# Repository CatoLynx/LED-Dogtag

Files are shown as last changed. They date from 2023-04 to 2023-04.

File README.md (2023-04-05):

# LED Dogtag
Here you can find the hardware and software for my LED display dogtag.

# Repository Structure
* The `hardware/LED_Dogtag_HW` directory contains the hardware design and production files for the dogtag
* The `hardware/LED_Driver_Evaluation` directory contains the hardware design and production files for an evaluation/test board for the LED driver IC

## Licenses
The hardware part of this repository is licensed under the CERN Open Hardware Licence Version 2 - Strongly Reciprocal (CERN-OHL-S v2) or later.
The software part is licensed under the GNU General Public License v3 (GPLv3).

## Design Tools used
* Schematics and printed circuit board designs were made using KiCad 7
* 3D models were created using SolidWorks 2023

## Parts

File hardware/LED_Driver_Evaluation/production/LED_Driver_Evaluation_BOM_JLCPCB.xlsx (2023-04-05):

Comment | Designator | Footprint | JLCPCB Part #（optional）
1µF | C1 | C0603 | C15849
100nF | C2 | C0603 | C14663
NH-B1010RGBT-HF | D1-66 | LED0404 | C2874113
51R | R1,R4,R7,R11,R14,R17 | R0402 | C25125
20R | R2,R3,R5,R6,R8,R9,R12,R13,R15,R16,R18,R20 | R0402 | C310255
100k | R10 | R0603 | C25803
10k | R19 | R0402 | C25744
IS31FL3743B | U1 | UQFN-40 | C2962218

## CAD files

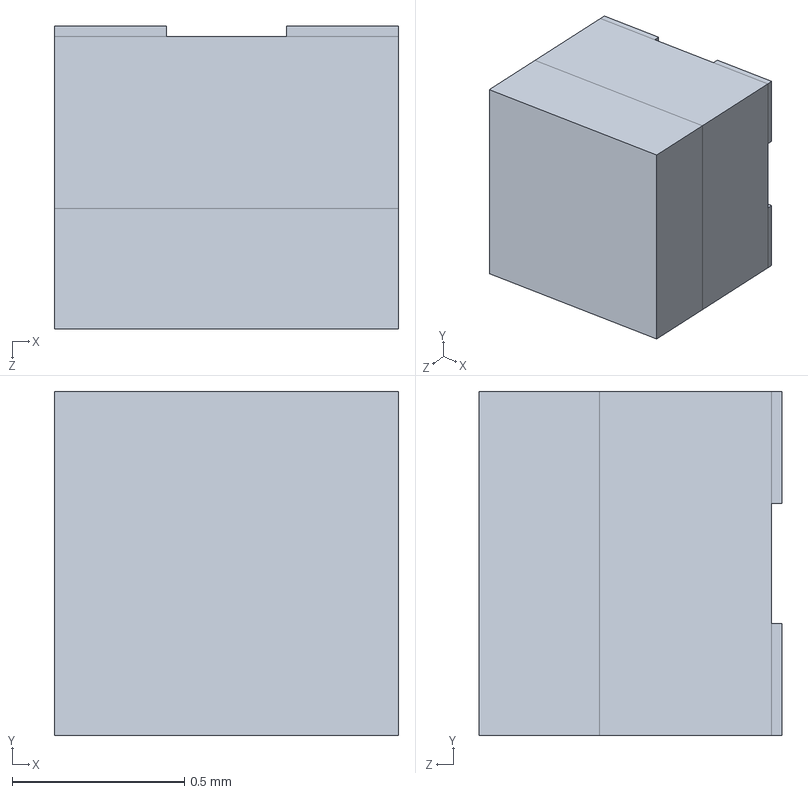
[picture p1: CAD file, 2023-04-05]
hardware/LED_Driver_Evaluation/3dmodels/LED_0404.SLDPRT
1.00 x 1.00 x 0.88 mm

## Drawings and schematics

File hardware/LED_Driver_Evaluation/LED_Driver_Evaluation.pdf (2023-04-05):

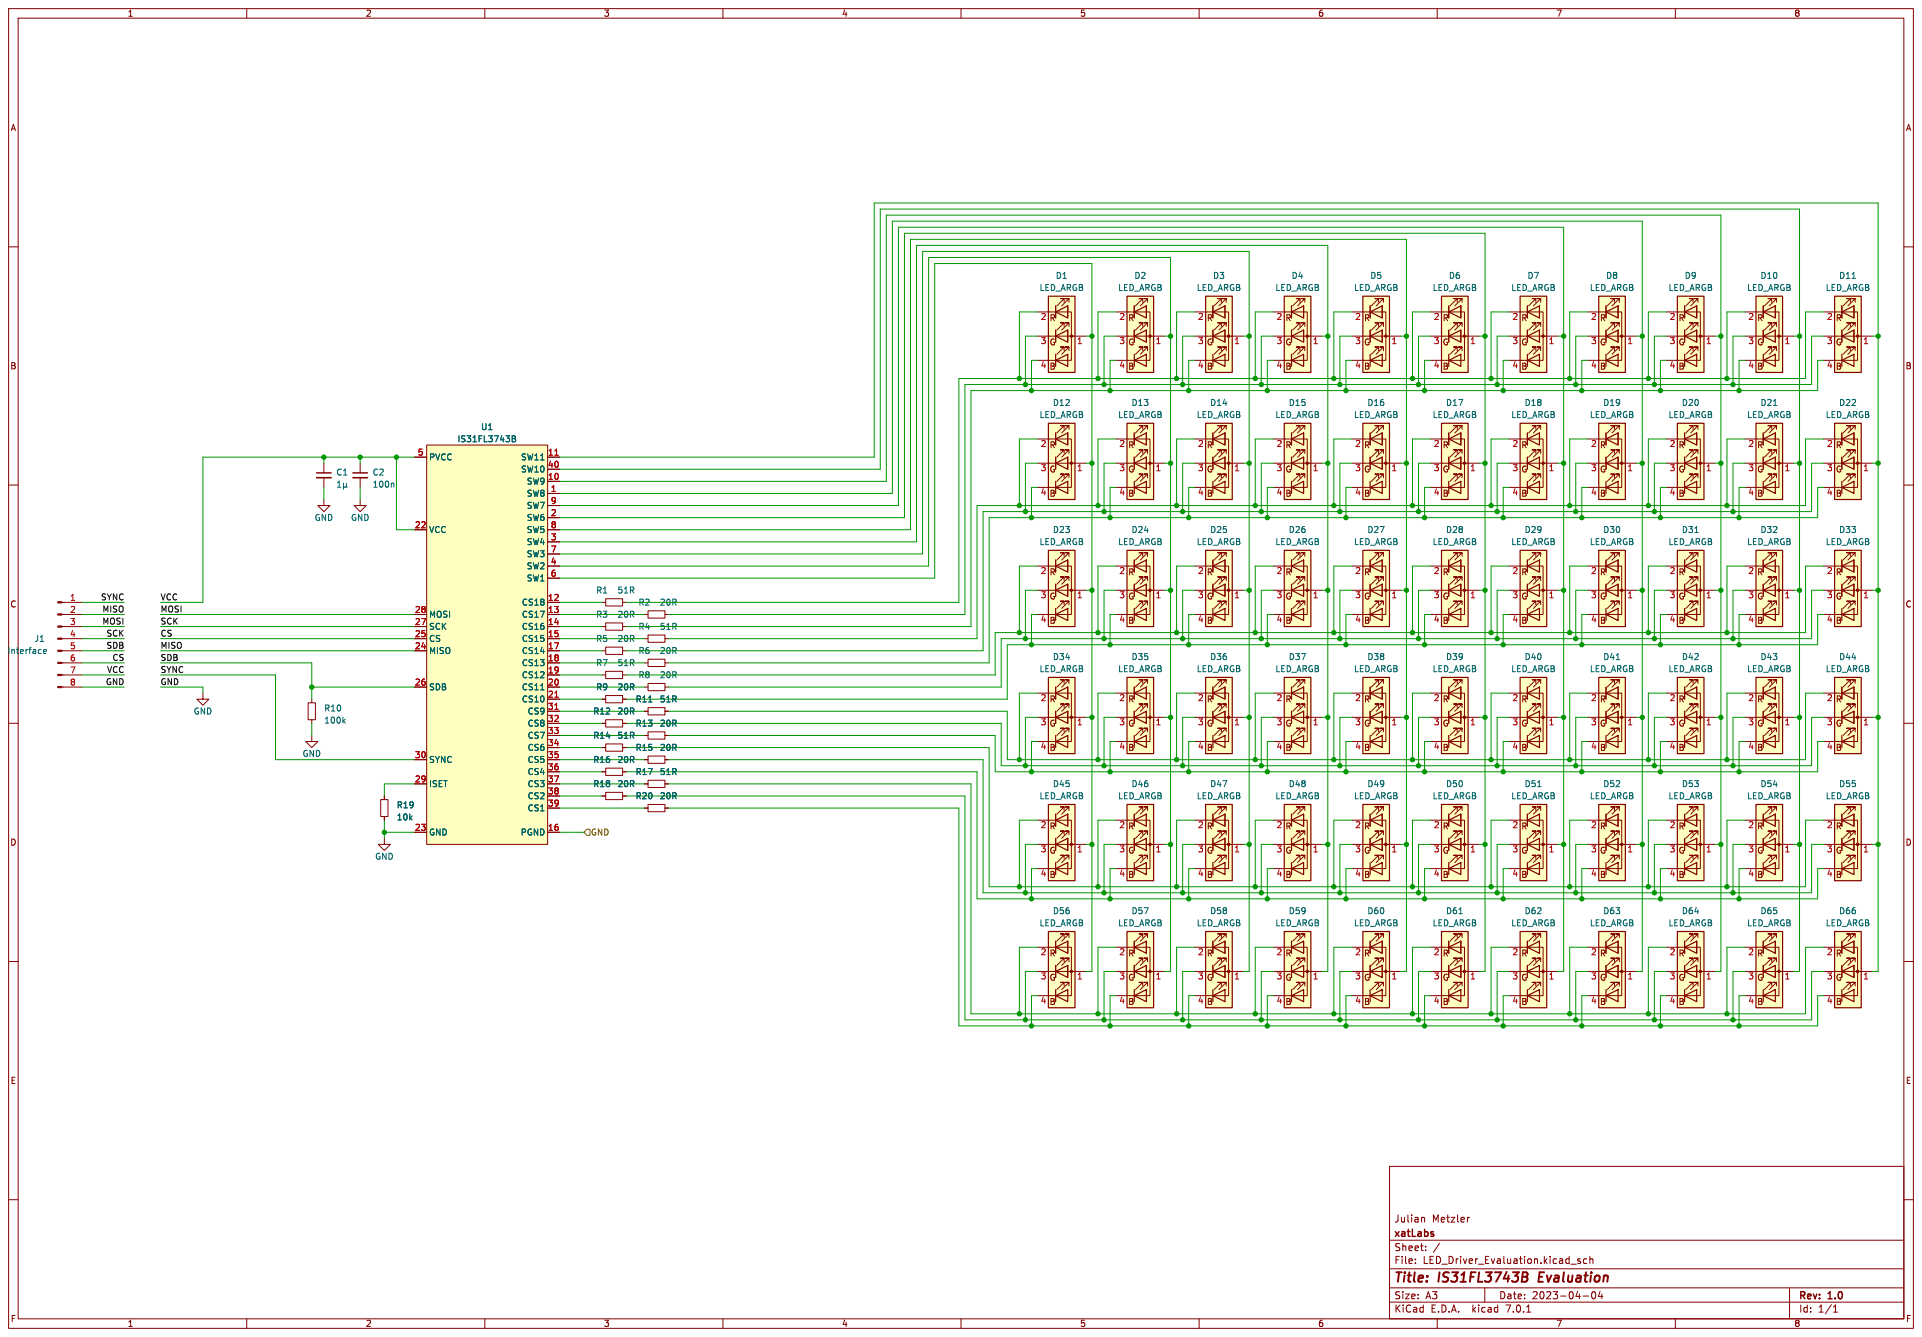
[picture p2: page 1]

SW8 1 SW9 10 SW11 11 CS18 12 CS17 13 CS16 14 CS15 15 PGND 16 CS14 17 CS13 18 CS12 19 SW6 2 CS11 20 CS10 21 VCC 22 GND 23 MISO 24 CS 25 SDB 26 SCK 27 MOSI 28

LED_ARGB GND

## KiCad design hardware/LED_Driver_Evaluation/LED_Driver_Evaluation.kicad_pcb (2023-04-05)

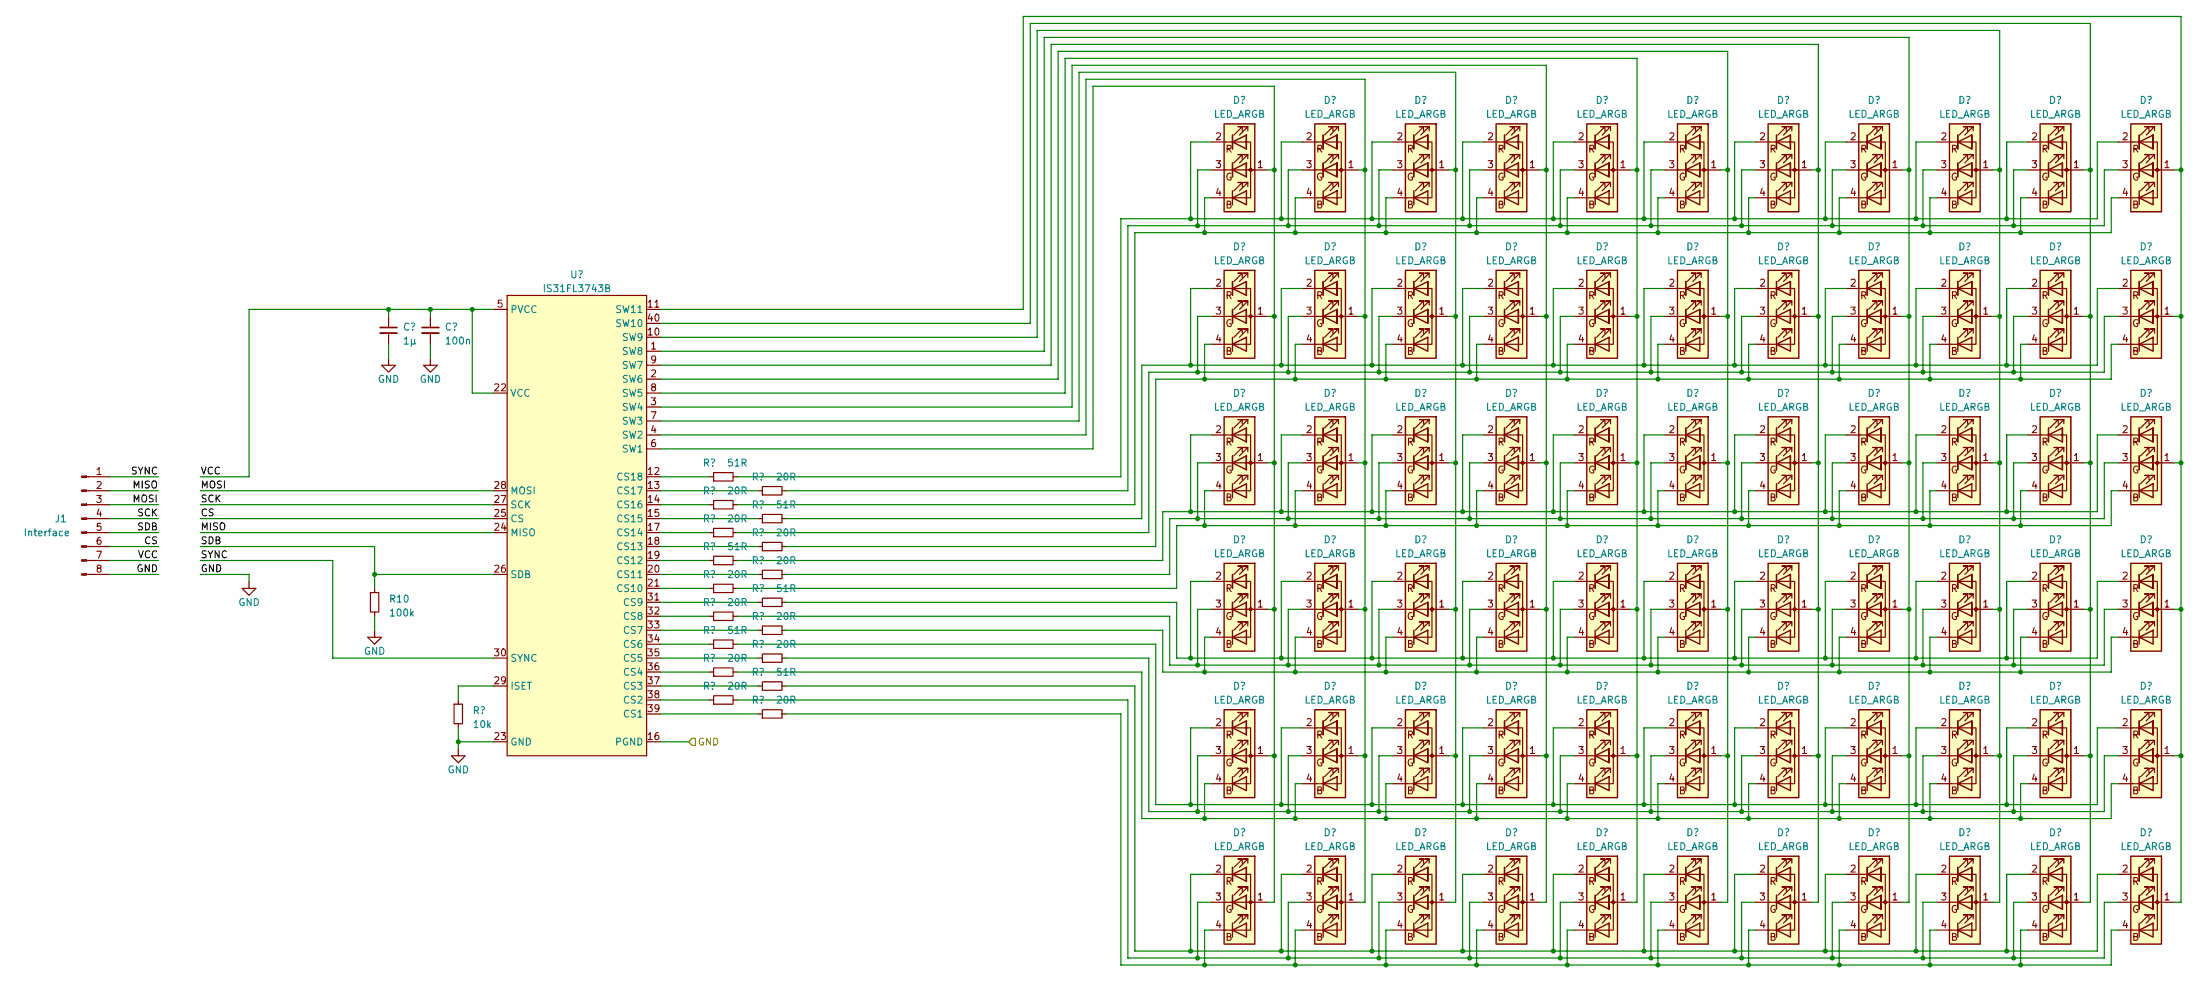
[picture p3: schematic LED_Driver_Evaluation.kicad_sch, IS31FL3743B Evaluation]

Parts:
C1: 1µ; C_0603_1608Metric
C2: 100n; C_0603_1608Metric
D1, D2, D3, D4, D5, D6, D7, D8, D9, D10, D11, D12, D13, D14, D15, D16, D17, D18, D19, D20, D21, D22, D23, D24, D25, D26, D27, D28, D29, D30, D31, D32, D33, D34, D35, D36, D37, D38, D39, D40, D41, D42, D43, D44, D45, D46, D47, D48, D49, D50, D51, D52, D53, D54, D55, D56, D57, D58, D59, D60, D61, D62, D63, D64, D65, D66: LED_ARGB; LED_0404
J1: Interface; PinHeader_1x08_P2.54mm_Vertical
R1, R4, R7, R11, R14, R17: 51R; R_0402_1005Metric
R2, R3, R5, R6, R8, R9, R12, R13, R15, R16, R18, R20: 20R; R_0402_1005Metric
R10: 100k; R_0603_1608Metric
R19: 10k; R_0402_1005Metric
U1: IS31FL3743B; UQFN-40-1EP_5x5mm_P0.4mm_EP3.8x3.8mm

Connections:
/CS: J1.6, U1.25 (CS)
/MISO: J1.2, U1.24 (MISO)
/MOSI: J1.3, U1.28 (MOSI)
/SCK: J1.4, U1.27 (SCK)
/SDB: J1.5, R10.1, U1.26 (SDB)
/SYNC: J1.1, U1.30 (SYNC)
/VCC: C1.1, C2.1, J1.7, U1.5 (PVCC), U1.22 (VCC)
GND: C1.2, C2.2, J1.8, R10.2, R19.2, U1.16 (PGND), U1.23 (GND), U1.41 (GND)
unnamed: D1.1 (A), D12.1 (A), D23.1 (A), D34.1 (A), D45.1 (A), D56.1 (A), U1.6 (SW1)
unnamed: D1.4 (BK), D2.4 (BK), D3.4 (BK), D4.4 (BK), D5.4 (BK), D6.4 (BK), D7.4 (BK), D8.4 (BK), D9.4 (BK), D10.4 (BK), D11.4 (BK), R3.2
unnamed: D1.3 (GK), D2.3 (GK), D3.3 (GK), D4.3 (GK), D5.3 (GK), D6.3 (GK), D7.3 (GK), D8.3 (GK), D9.3 (GK), D10.3 (GK), D11.3 (GK), R2.2
unnamed: D1.2 (RK), D2.2 (RK), D3.2 (RK), D4.2 (RK), D5.2 (RK), D6.2 (RK), D7.2 (RK), D8.2 (RK), D9.2 (RK), D10.2 (RK), D11.2 (RK), R1.2
unnamed: D10.1 (A), D21.1 (A), D32.1 (A), D43.1 (A), D54.1 (A), D65.1 (A), U1.40 (SW10)
unnamed: D11.1 (A), D22.1 (A), D33.1 (A), D44.1 (A), D55.1 (A), D66.1 (A), U1.11 (SW11)
unnamed: D12.4 (BK), D13.4 (BK), D14.4 (BK), D15.4 (BK), D16.4 (BK), D17.4 (BK), D18.4 (BK), D19.4 (BK), D20.4 (BK), D21.4 (BK), D22.4 (BK), R6.2
unnamed: D12.3 (GK), D13.3 (GK), D14.3 (GK), D15.3 (GK), D16.3 (GK), D17.3 (GK), D18.3 (GK), D19.3 (GK), D20.3 (GK), D21.3 (GK), D22.3 (GK), R5.2
unnamed: D12.2 (RK), D13.2 (RK), D14.2 (RK), D15.2 (RK), D16.2 (RK), D17.2 (RK), D18.2 (RK), D19.2 (RK), D20.2 (RK), D21.2 (RK), D22.2 (RK), R4.2
unnamed: D2.1 (A), D13.1 (A), D24.1 (A), D35.1 (A), D46.1 (A), D57.1 (A), U1.4 (SW2)
unnamed: D3.1 (A), D14.1 (A), D25.1 (A), D36.1 (A), D47.1 (A), D58.1 (A), U1.7 (SW3)
unnamed: D4.1 (A), D15.1 (A), D26.1 (A), D37.1 (A), D48.1 (A), D59.1 (A), U1.3 (SW4)
unnamed: D5.1 (A), D16.1 (A), D27.1 (A), D38.1 (A), D49.1 (A), D60.1 (A), U1.8 (SW5)
unnamed: D6.1 (A), D17.1 (A), D28.1 (A), D39.1 (A), D50.1 (A), D61.1 (A), U1.2 (SW6)
unnamed: D7.1 (A), D18.1 (A), D29.1 (A), D40.1 (A), D51.1 (A), D62.1 (A), U1.9 (SW7)
unnamed: D8.1 (A), D19.1 (A), D30.1 (A), D41.1 (A), D52.1 (A), D63.1 (A), U1.1 (SW8)
unnamed: D9.1 (A), D20.1 (A), D31.1 (A), D42.1 (A), D53.1 (A), D64.1 (A), U1.10 (SW9)
unnamed: D23.4 (BK), D24.4 (BK), D25.4 (BK), D26.4 (BK), D27.4 (BK), D28.4 (BK), D29.4 (BK), D30.4 (BK), D31.4 (BK), D32.4 (BK), D33.4 (BK), R9.2
unnamed: D23.3 (GK), D24.3 (GK), D25.3 (GK), D26.3 (GK), D27.3 (GK), D28.3 (GK), D29.3 (GK), D30.3 (GK), D31.3 (GK), D32.3 (GK), D33.3 (GK), R8.2
unnamed: D23.2 (RK), D24.2 (RK), D25.2 (RK), D26.2 (RK), D27.2 (RK), D28.2 (RK), D29.2 (RK), D30.2 (RK), D31.2 (RK), D32.2 (RK), D33.2 (RK), R7.2
unnamed: D34.4 (BK), D35.4 (BK), D36.4 (BK), D37.4 (BK), D38.4 (BK), D39.4 (BK), D40.4 (BK), D41.4 (BK), D42.4 (BK), D43.4 (BK), D44.4 (BK), R13.2
unnamed: D34.3 (GK), D35.3 (GK), D36.3 (GK), D37.3 (GK), D38.3 (GK), D39.3 (GK), D40.3 (GK), D41.3 (GK), D42.3 (GK), D43.3 (GK), D44.3 (GK), R12.2
unnamed: D34.2 (RK), D35.2 (RK), D36.2 (RK), D37.2 (RK), D38.2 (RK), D39.2 (RK), D40.2 (RK), D41.2 (RK), D42.2 (RK), D43.2 (RK), D44.2 (RK), R11.2
unnamed: D45.4 (BK), D46.4 (BK), D47.4 (BK), D48.4 (BK), D49.4 (BK), D50.4 (BK), D51.4 (BK), D52.4 (BK), D53.4 (BK), D54.4 (BK), D55.4 (BK), R16.2
unnamed: D45.3 (GK), D46.3 (GK), D47.3 (GK), D48.3 (GK), D49.3 (GK), D50.3 (GK), D51.3 (GK), D52.3 (GK), D53.3 (GK), D54.3 (GK), D55.3 (GK), R15.2
unnamed: D45.2 (RK), D46.2 (RK), D47.2 (RK), D48.2 (RK), D49.2 (RK), D50.2 (RK), D51.2 (RK), D52.2 (RK), D53.2 (RK), D54.2 (RK), D55.2 (RK), R14.2
unnamed: D56.4 (BK), D57.4 (BK), D58.4 (BK), D59.4 (BK), D60.4 (BK), D61.4 (BK), D62.4 (BK), D63.4 (BK), D64.4 (BK), D65.4 (BK), D66.4 (BK), R20.2
unnamed: D56.3 (GK), D57.3 (GK), D58.3 (GK), D59.3 (GK), D60.3 (GK), D61.3 (GK), D62.3 (GK), D63.3 (GK), D64.3 (GK), D65.3 (GK), D66.3 (GK), R18.2
unnamed: D56.2 (RK), D57.2 (RK), D58.2 (RK), D59.2 (RK), D60.2 (RK), D61.2 (RK), D62.2 (RK), D63.2 (RK), D64.2 (RK), D65.2 (RK), D66.2 (RK), R17.2
unnamed: R20.1, U1.39 (CS1)
unnamed: R18.1, U1.38 (CS2)
unnamed: R17.1, U1.37 (CS3)
unnamed: R16.1, U1.36 (CS4)
unnamed: R15.1, U1.35 (CS5)
unnamed: R14.1, U1.34 (CS6)
unnamed: R13.1, U1.33 (CS7)
unnamed: R12.1, U1.32 (CS8)
unnamed: R11.1, U1.31 (CS9)
unnamed: R9.1, U1.21 (CS10)
unnamed: R8.1, U1.20 (CS11)
unnamed: R7.1, U1.19 (CS12)
unnamed: R6.1, U1.18 (CS13)
unnamed: R5.1, U1.17 (CS14)
unnamed: R4.1, U1.15 (CS15)
unnamed: R3.1, U1.14 (CS16)
unnamed: R2.1, U1.13 (CS17)
unnamed: R1.1, U1.12 (CS18)
unnamed: R19.1, U1.29 (ISET)

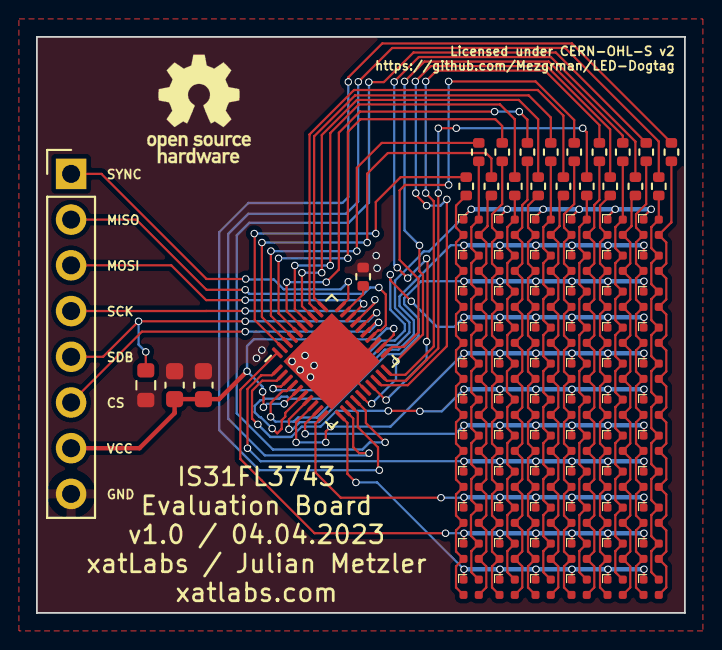
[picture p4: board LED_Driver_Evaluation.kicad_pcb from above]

Board: 2 copper layers, 36.0 x 32.0 mm, 90 parts (0 on the bottom side), 56 nets.

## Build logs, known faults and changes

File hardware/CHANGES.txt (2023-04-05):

This is a placeholder file for documenting your changes compared to the original design files, as required by the CERN-OHL-S v2 license.

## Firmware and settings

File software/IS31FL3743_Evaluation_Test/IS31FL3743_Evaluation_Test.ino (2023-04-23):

/*
  Copyright (C) 2023 Julian Metzler

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
  You should have received a copy of the GNU General Public License
  along with this program.  If not, see <http://www.gnu.org/licenses/>.
*/

#include "is31fl3743.h"

// Generated by image2cpp
const uint32_t image[] = {
// 'test', 6x11px
0x00ff0100, 0x00ff0001, 0x00ff2401, 0x00ff4801, 0x00ff8f01, 0x00ffd601, 
0x00ff2400, 0x00ff6b00, 0x00ff8f01, 0x00ffd601, 0x00e2ff01, 0x009aff00, 
0x00ffb300, 0x00ffd601, 0x00e2ff00, 0x009bff01, 0x0054ff00, 0x000dff00, 
0x00e2ff00, 0x009bff00, 0x0054ff00, 0x000cff00, 0x0000ff3c, 0x0000ff83, 
0x0053ff01, 0x000cff01, 0x0001ff3c, 0x0001ff83, 0x0001ffca, 0x0000ffee, 
0x0001ff3c, 0x0000ff83, 0x0000ffcb, 0x0000eeff, 0x0001caff, 0x000083ff, 
0x0000ffca, 0x0000edff, 0x0001a7ff, 0x000183ff, 0x00003cff, 0x000d01ff, 
0x0000a7ff, 0x000160ff, 0x00003cff, 0x000d00ff, 0x005401ff, 0x009a00ff, 
0x000018ff, 0x000c01ff, 0x005300ff, 0x009b01ff, 0x00e200ff, 0x00ff00d6, 
0x005300ff, 0x009a00ff, 0x00e201ff, 0x00ff01d6, 0x00ff008f, 0x00ff006b, 
0x00e200ff, 0x00ff01d6, 0x00ff008f, 0x00ff0048, 0x00ff0124, 0x00ff0100
};

const uint8_t gammaTable[32] = {
  0, 1, 2, 3, 6, 10, 13, 18, 22, 28, 33, 39, 46, 53, 61, 69, 78, 86, 96, 106, 116, 126, 138, 149, 161, 173, 186, 199, 212, 226, 240, 255
};

void setup() {
  is31fl3743_init();
  is31fl3743_setGlobalBrightness(4);

  for (uint8_t i = 0; i < 3*6*11; i++) {
    is31fl3743_setPixelScalingFactor(i, 0xFF);
  }

  for (uint8_t y = 0; y < 11; y++) {
    for (uint8_t x = 0; x < 6; x++) {
      uint8_t i = y * 6 + x;
      is31fl3743_setPixelRGB(x, y, image[i]);
    }
  }
}

void loop() {
  // Display a pink horizontal line moving up and down on a dim white background
  /*for (uint8_t y = 0; y < 11; y++) {
    for (uint16_t i = 1; i <= 3*6*11; i++) {
      uint8_t data = (((i-1) / 18) == y) ? (((i)%3 == 0 || (i+2)%3 == 0) ? 0xFF : 0x08) : 0x08;
      is31fl3743_write(0, i, &data, 1); // Write to PWM register
    }
    delay(20);
  }
  for (int8_t y = 10; y >= 0; y--) {
    for (uint16_t i = 1; i <= 3*6*11; i++) {
      uint8_t data = (((i-1) / 18) == y) ? (((i)%3 == 0 || (i+2)%3 == 0) ? 0xFF : 0x08) : 0x08;
      is31fl3743_write(0, i, &data, 1); // Write to PWM register
    }
    delay(20);
  }*/

  // Breathing effect with global brightness
  for (uint8_t i = 0; i < 32; i++) {
    uint8_t data = gammaTable[i];
    is31fl3743_write(2, 0x01, &data, 1); // Write to global current register at 0x01
    delay(50);
  }
  for (uint8_t i = 0; i < 32; i++) {
    uint8_t data = gammaTable[31-i];
    is31fl3743_write(2, 0x01, &data, 1); // Write to global current register at 0x01
    delay(50);
  }
}

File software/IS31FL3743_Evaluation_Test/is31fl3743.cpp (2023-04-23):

/*
  Copyright (C) 2023 Julian Metzler

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
  You should have received a copy of the GNU General Public License
  along with this program.  If not, see <http://www.gnu.org/licenses/>.
*/

#include "is31fl3743.h"
#include <SPI.h>

SPIClass spi(HSPI);

void is31fl3743_init() {
  pinMode(PIN_SDB, OUTPUT);
  pinMode(PIN_CS, OUTPUT);
  digitalWrite(PIN_SDB, HIGH);
  digitalWrite(PIN_CS, HIGH);
  spi.begin(PIN_SCK, PIN_MISO, PIN_MOSI);

  is31fl3743_reset();

  uint8_t data = 0b00001001; // No shutdown, No OSD, all 11 drivers enabled
  is31fl3743_write(2, 0x00, &data, 1); // Write to configuration register at 0x00

  data = 0b00110011; // 0° phase shift, 2k SW pulldown when off, 2k CS pullup when off
  is31fl3743_write(2, 0x02, &data, 1); // Write to pullup/down register at 0x02
}

void is31fl3743_write(uint8_t page, uint8_t addr, uint8_t* data, uint16_t dataLen) {
  uint8_t firstByte = 0b01010000;
  firstByte |= (page & 0x0F);

  digitalWrite(PIN_CS, LOW);
  spi.beginTransaction(SPISettings());

  spi.write(firstByte);
  spi.write(addr);
  for (uint32_t i = 0; i < dataLen; i++) {
    spi.write(data[i]);
  }

  spi.endTransaction();
  digitalWrite(PIN_CS, HIGH);
}

void is31fl3743_read(uint8_t page, uint8_t addr, uint8_t* data, uint16_t dataLen) {
  uint8_t firstByte = 0b11010000;
  firstByte |= (page & 0x0F);

  digitalWrite(PIN_CS, LOW);
  spi.beginTransaction(SPISettings());

  spi.write(firstByte);
  spi.write(addr);
  for (uint32_t i = 0; i < dataLen; i++) {
    data[i] = spi.transfer(0x00);
  }

  spi.endTransaction();
  digitalWrite(PIN_CS, HIGH);
}

void is31fl3743_reset() {
  uint8_t data = 0xAE; // Reset
  is31fl3743_write(2, 0x2F, &data, 1);
}

void is31fl3743_setGlobalBrightness(uint8_t brightness) {
  is31fl3743_write(2, 0x01, &brightness, 1);
}

void is31fl3743_setPixelScalingFactor(uint8_t pixel, uint8_t scalingFactor) {
  // pixel is the 0-based index of the pixel register to write
  is31fl3743_write(1, pixel+1, &scalingFactor, 1);
}

void is31fl3743_setPixelRGB(uint8_t x, uint8_t y, uint32_t color) {
  // color: uint32_t, 00RRGGBB
  uint8_t i = y * 6 + x;
  // Color order: BGR
  uint8_t data[3] = { (color & 0xFF), ((color >> 8) & 0xFF), ((color >> 16) & 0xFF) };
  is31fl3743_write(0, i*3+1, data, 3); // Write to PWM registers
}

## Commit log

2023-04-05 Initial commit containing the LED driver evaluation board
    [LED_0404.SLDPRT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]
2023-04-23 Add production files for LED driver evaluation board
    [LED_Dogtag_HW-B_Cu.gbr, LED_Dogtag_HW-B_Mask.gbr, LED_Dogtag_HW-B_Paste.gbr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]
2023-04-23 Add Arduino test software for IS31FL3743 evaluation board

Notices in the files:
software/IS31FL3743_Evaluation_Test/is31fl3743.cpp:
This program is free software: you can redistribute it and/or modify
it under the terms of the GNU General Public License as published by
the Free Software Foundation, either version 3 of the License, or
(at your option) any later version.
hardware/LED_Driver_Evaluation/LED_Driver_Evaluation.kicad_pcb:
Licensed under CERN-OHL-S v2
